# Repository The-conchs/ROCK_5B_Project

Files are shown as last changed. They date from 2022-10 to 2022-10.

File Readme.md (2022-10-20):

# ROCK_5B 外壳

		这个项目是ROCK_5B SBC 的外壳   适用版本是1.41（准量产版本

## 注意！！！

		如果想适用于量产版本的话就需要改动TF卡槽部分（因为我没有量产版本的ROCK 5B所以我无法进行测量，但是我提供了模型工程文件，可以自行进行修改

		我自己没有3D打印机，采用的是嘉立创三维猴的3D打印代加工服务

		顶盖 ，底座 ，网络模块 采用的是SLA (光固化)加工的剩下的均是尼龙 3D打印（具体什么方式我不知道因为顶盖 ，底座 ，网络模块这个三个工件比较厚，强度很高，不用担心断裂或者形变，但是其他的一些零件有些比较脆弱，所以需要使用尼龙3D打印

		强烈建议在打印模型之前对IO侧的开孔间距进行测量，因为当前模型的间距是从我自己的ROCK 5B上测量得到的。

## 成品展示

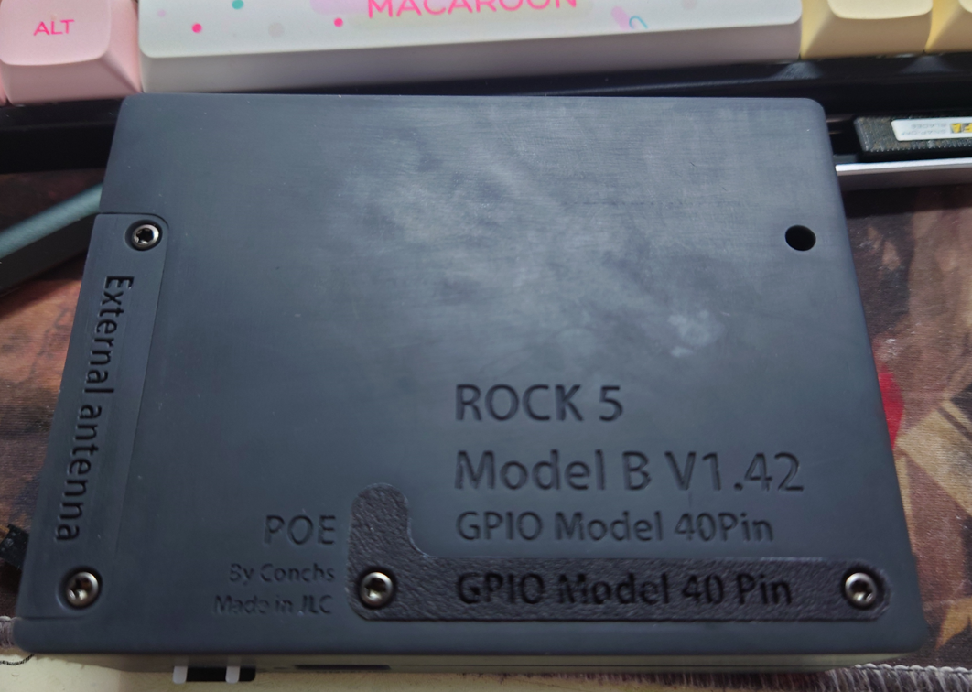
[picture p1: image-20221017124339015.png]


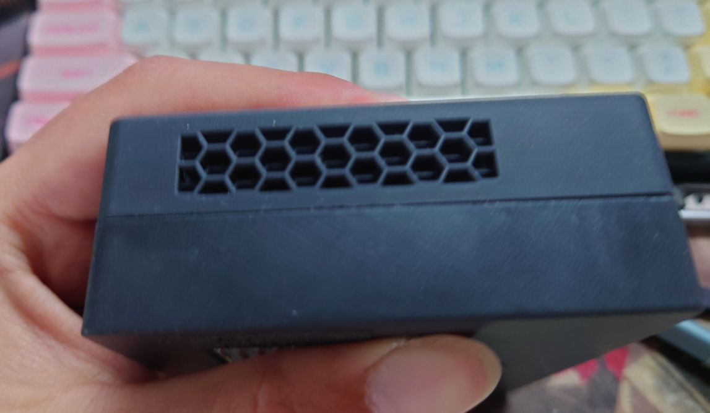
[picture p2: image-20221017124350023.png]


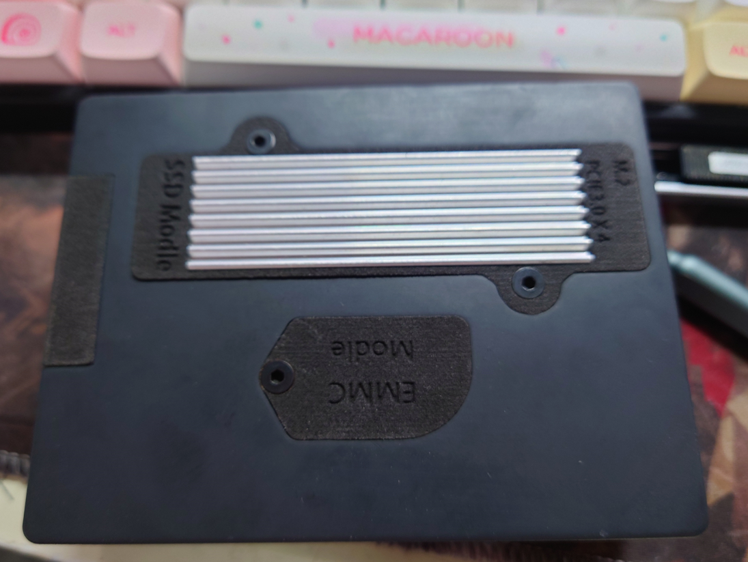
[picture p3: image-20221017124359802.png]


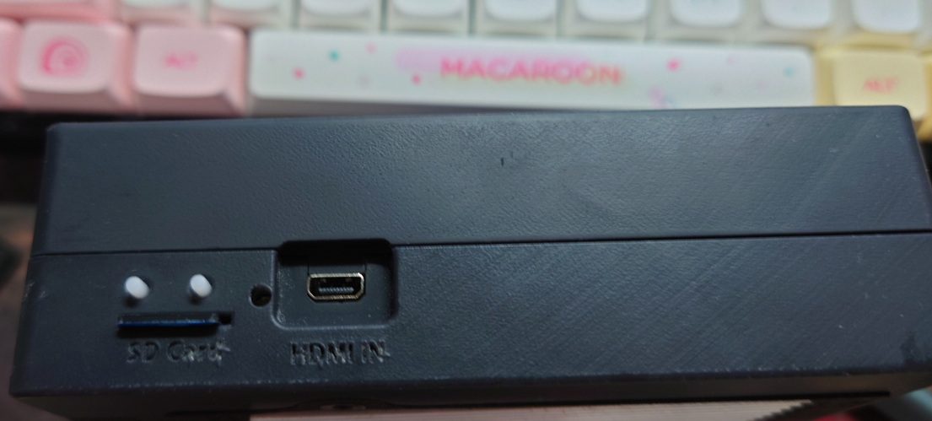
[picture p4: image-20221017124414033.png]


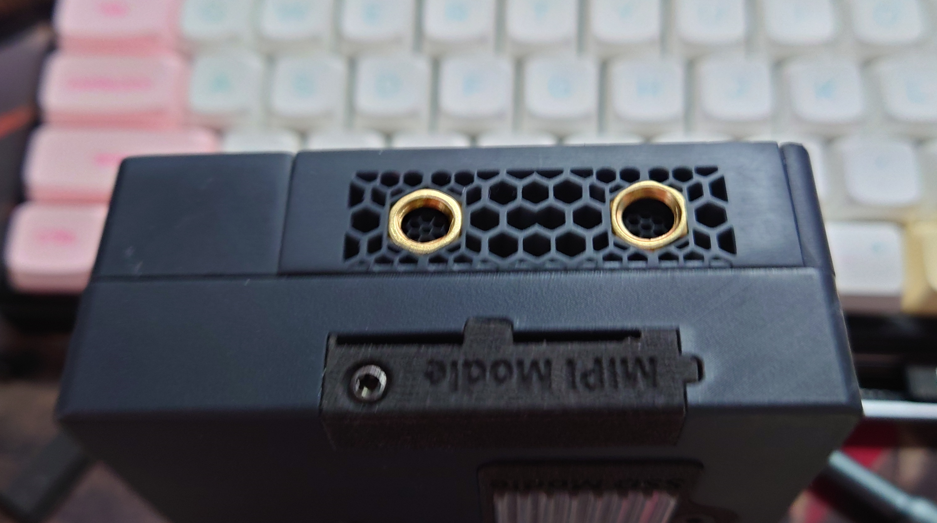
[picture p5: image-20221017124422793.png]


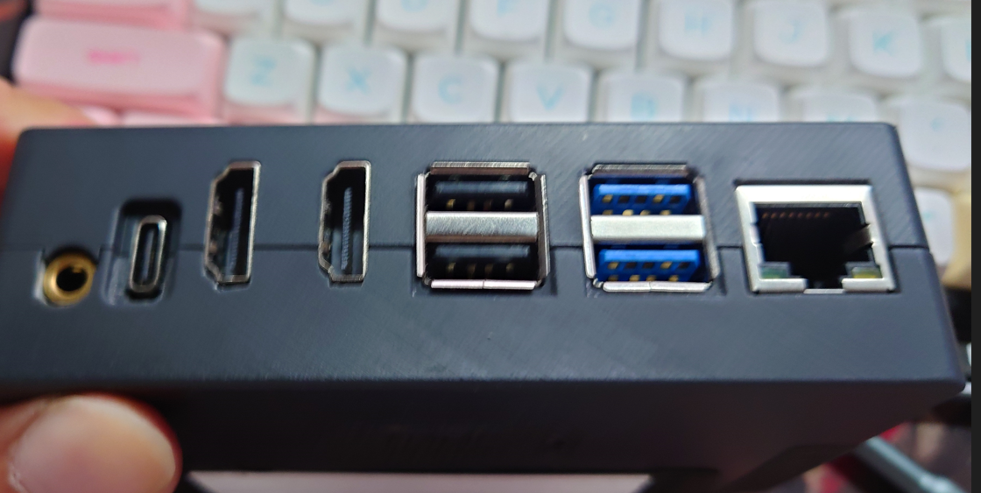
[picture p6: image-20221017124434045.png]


以上就是最终的成品展示。

现在还缺少压力测试，因为散热器还没有进行固定

## 安装

因为我已经完成了模型的安装，有些安装是不可逆的所以我无法展示出来，为了方便我采用模型的方式来展示安装过程

### 安装自攻牙套

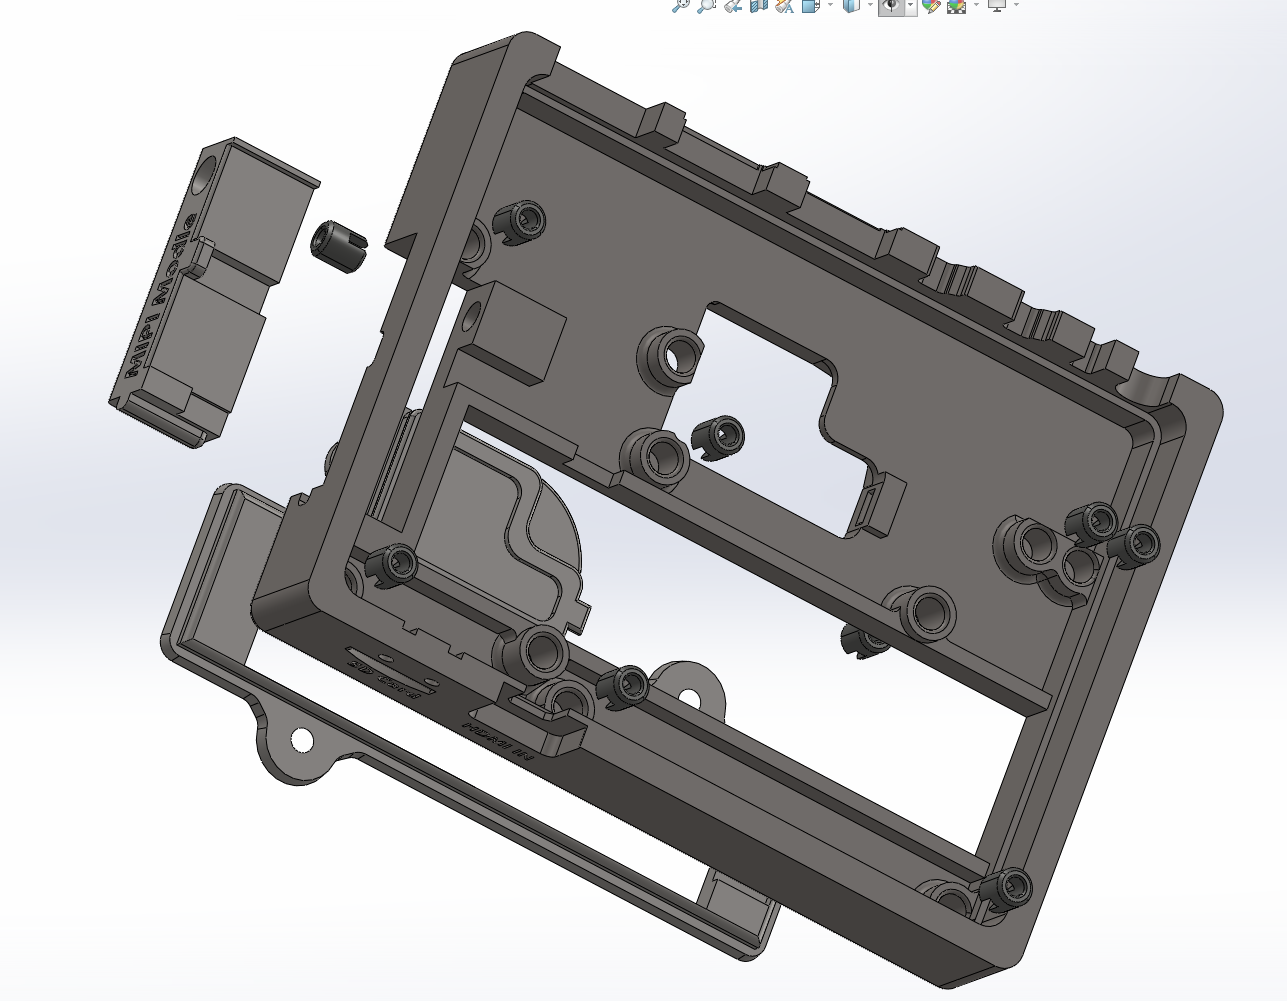
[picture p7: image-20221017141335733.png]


在底座模型上安装自攻牙套（规格 L6   M3  ）

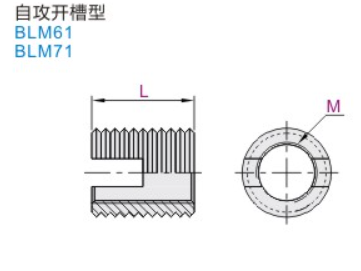
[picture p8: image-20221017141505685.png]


安装方法

1.有专门的安装自攻牙套的工具（推荐，成功率高，难度低，但是要花额外的钱去买工具）

2.准备一个较长的螺丝（最好是内六角的）和一个螺母（均是M3) 然后和牙套一起组装起来

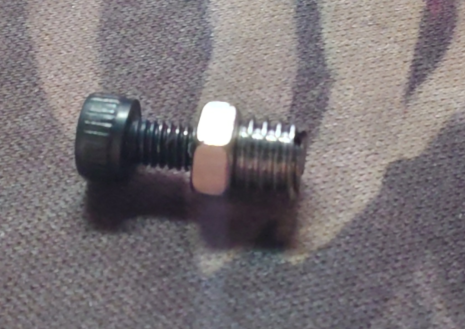
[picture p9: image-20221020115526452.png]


就像这样（因为没用多余的自攻牙套了所以用普通的牙套演示

然后想拧螺丝钉一样将它安装进底座，然后在拧松螺母，这样螺丝就能退出牙套了

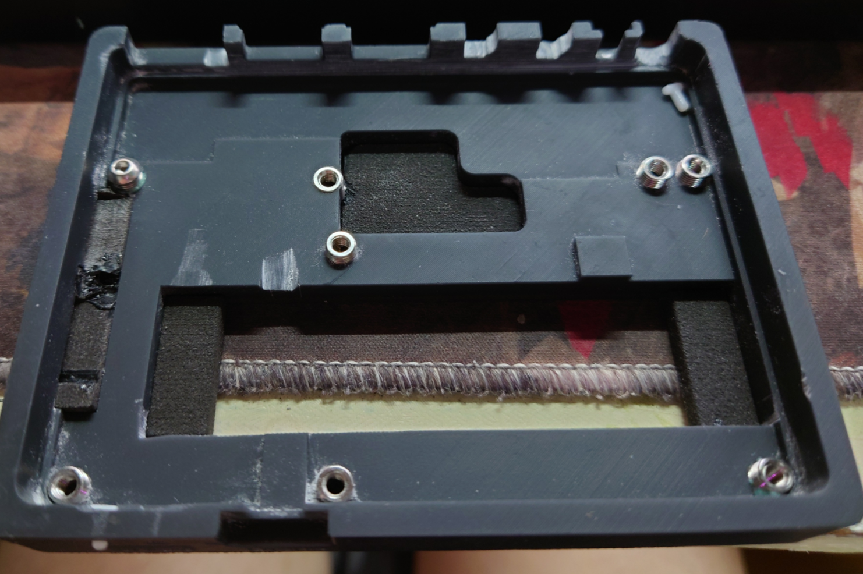
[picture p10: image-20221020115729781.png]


		安装完成就像这样（如果打滑了也不要紧张，可以加入一些AB胶来进行固定这样就能达到类似的效果）

### 		安装底座

		接下来就是打磨了，因为每个人的ROCK5B的IO接口间距都不太一样，所以都需要打磨，打磨到能完整放进底座就算成功了（这个就需要耐心和经验了）

		记得要检查M.2 SSD能否正常安装和拆卸（在ROCK5B安装在底座上的情况下

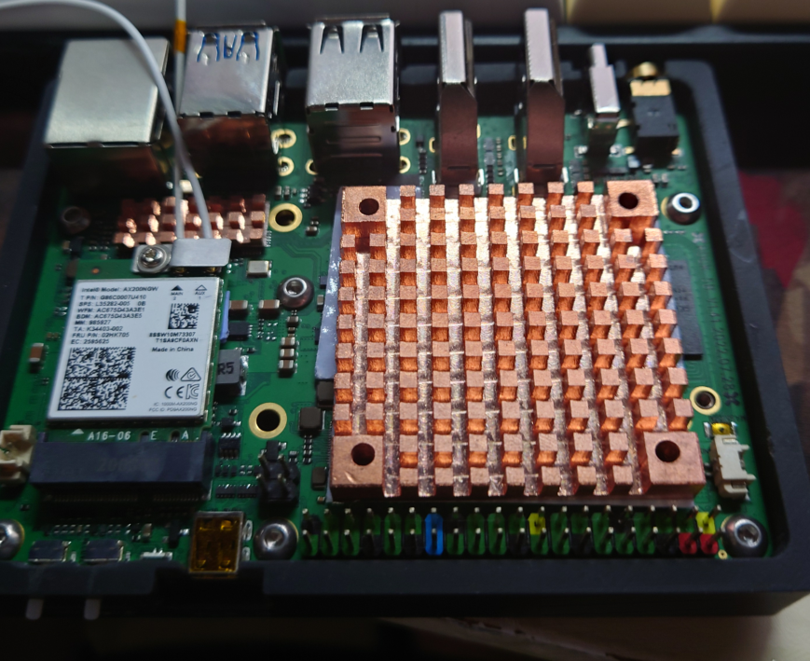
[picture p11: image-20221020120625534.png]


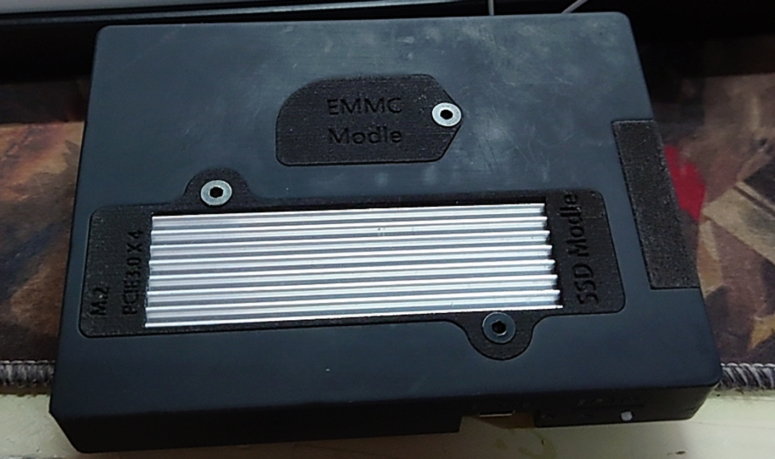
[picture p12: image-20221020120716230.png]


要记得安装按钮延长组件（这个也是需要微调的

### 安装顶盖

到了这一步就能开始安装顶盖了

顶盖的步骤和底座相似，需要打磨IO接口的位置，是否能够让顶盖轻松安装在ROCK5B上，剩下的就是固定螺丝了，然后检查外壳是否还需要调整完成之后就可以准备安装散热器了。（记得贴上内置天线哦，也可以使用外置天线）

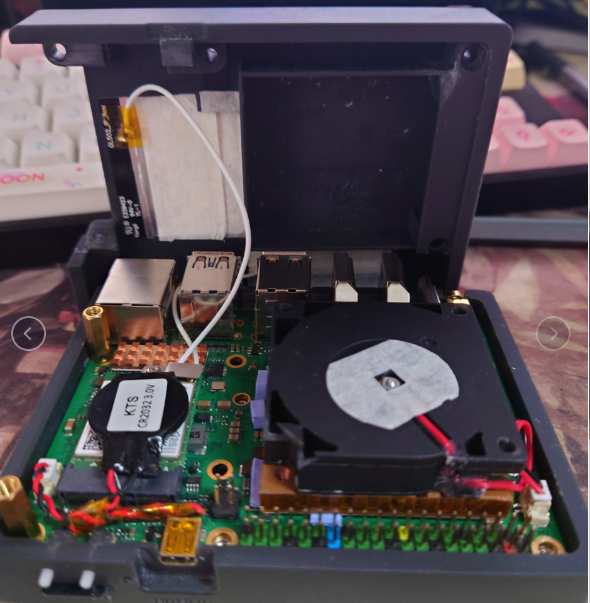
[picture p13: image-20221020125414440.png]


		散热器使用的是45 *45 *6mm 的散热器，风扇使用的是4510涡轮风扇，起初我打算使用螺丝将散热器和风扇组装起来，发现这样会让外壳无法正常安装，所以就使用双面胶将二者粘起来（可能会有安全隐患，但目前使用还没有出现任何问题，感觉强烈的震动可能会出现问题）

		首先在rock5B 上除了RK3588 SOC以外的位置贴上2mm的硅胶垫（因为它们高度都不相同，所以需要使用硅胶垫去弥补它们之间的差距）然后在散热器的底面贴上导热胶布（0.1mm厚）然后把散热器装入顶盖的方形凹槽中，再装上rock5B这样就能让散热器粘在rock5B上了（因为各种各样的问题让我不愿意用螺丝固定散热器，虽然我也知道这不是一个好办法）

PS:散热器左侧有两颗小芯片没有覆盖到，据说是SOC的供电芯片，所以我打算使用超厚的硅胶垫来充当散热器贴上去了（反正官方也没用强调需要对其进行散热，想必发热应该不会很严重所以就只是象征性地贴上了

到此就算完成外壳和散热器的组装了

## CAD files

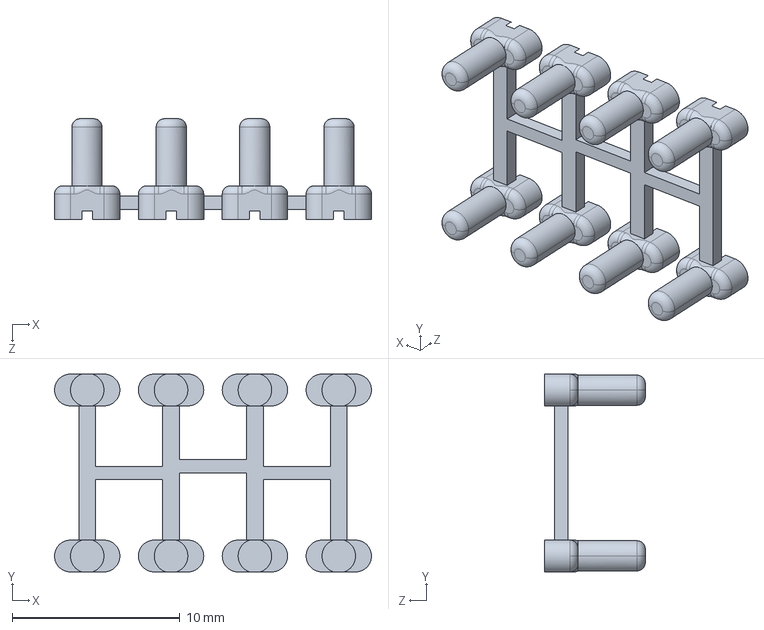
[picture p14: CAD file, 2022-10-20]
STEP文件/按钮延长组件.STEP
18.9 x 11.8 x 6.00 mm

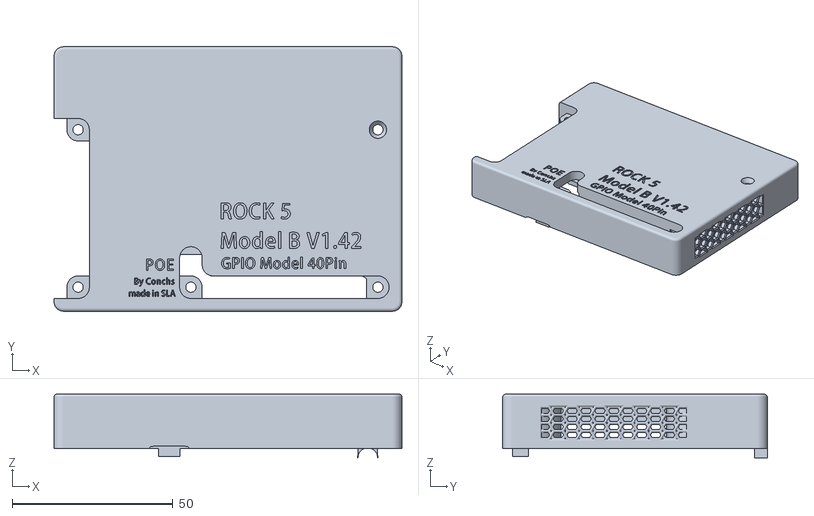
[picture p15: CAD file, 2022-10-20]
STL文件/ROCK-5B顶盖.STL
108.3 x 82.3 x 19.9

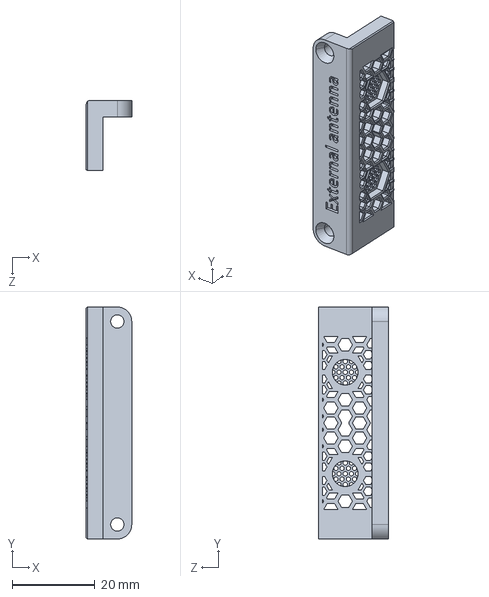
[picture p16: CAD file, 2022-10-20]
STEP文件/天线模块.STEP
11.0 x 56.0 x 17.0 mm

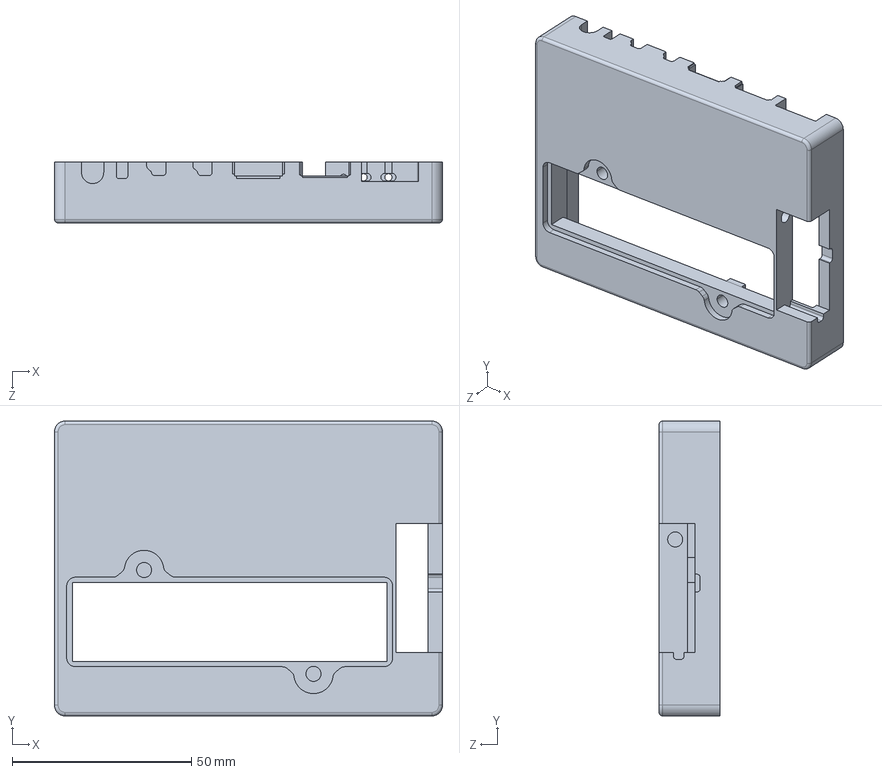
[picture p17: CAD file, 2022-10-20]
STEP文件/ROCK-5B底座.STEP
108.3 x 82.3 x 17.0 mm

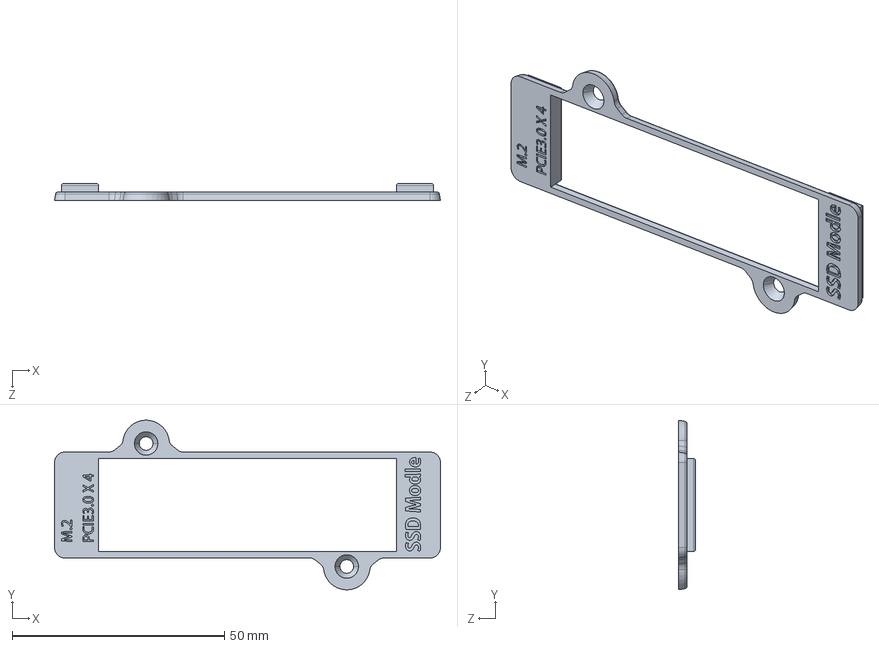
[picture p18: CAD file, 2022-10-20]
STEP文件/M.2盖板.STEP
91.0 x 40.0 x 4.00 mm

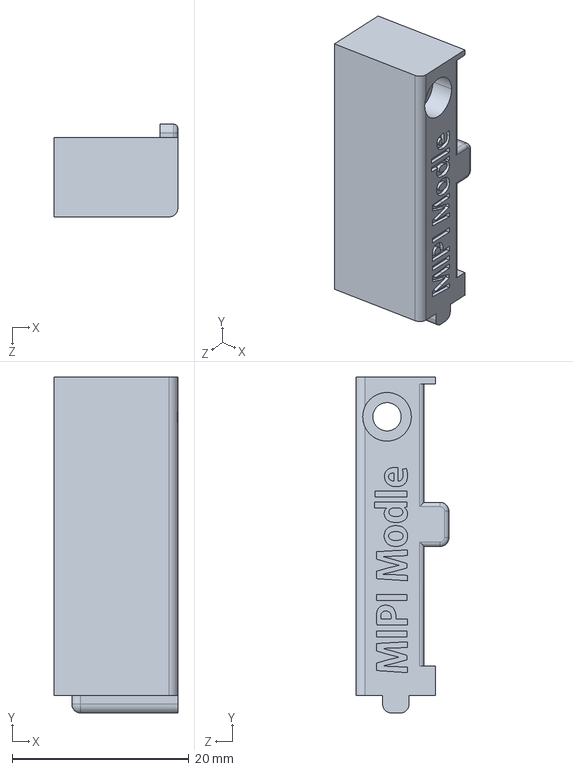
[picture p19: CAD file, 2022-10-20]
STEP文件/MIPI 盖板.STEP
14.0 x 38.0 x 10.5 mm

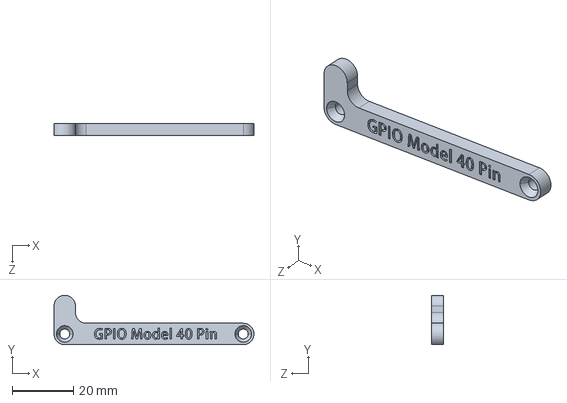
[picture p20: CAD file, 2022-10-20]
STEP文件/GPIO 盖板.STEP
65.2 x 16.1 x 4.00 mm

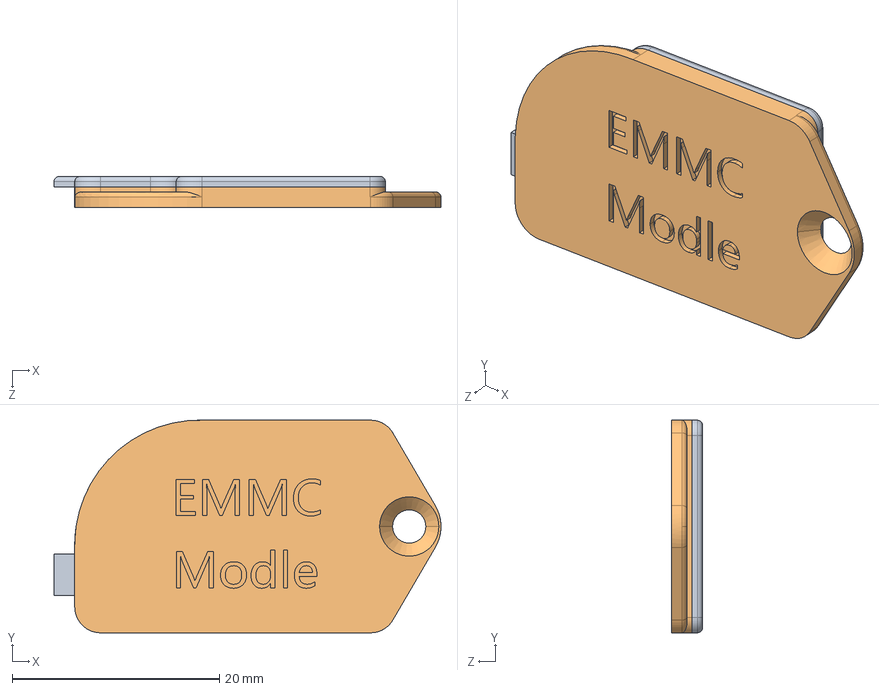
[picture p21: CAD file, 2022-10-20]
STEP文件/EMMC盖板.STEP
37.4 x 20.5 x 3.00 mm

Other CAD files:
STL文件/EMMC盖板.STL
STL文件/GPIO 盖板.STL
STL文件/M.2盖板.STL
STL文件/MIPI 盖板.STL
STL文件/ROCK-5B底座.STL
STL文件/天线模块.STL
STL文件/按钮延长组件.STL

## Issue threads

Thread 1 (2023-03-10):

版本问题

flymzero, 2023-03-10:
老哥我看你文字描述是1.41，我看图片壳上显示1.42，版本是哪个哈😄

The-conchs, 2023-03-23:
emmmm。。。。。这个版本指的是rock5B的版本，模型文件还是1.41的那个（可能外观写的还是1.42）不过问题不大，都能用的1.41和1.42
Rock5B都能用（抱歉哈~这个项目只是我一时兴起推上去的，最近又因为工作忙就一直没有维护

flyzero ***@***.***> 于 2023年3月10日周五 上午9:08写道：

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

Closed 2023-03-23.
